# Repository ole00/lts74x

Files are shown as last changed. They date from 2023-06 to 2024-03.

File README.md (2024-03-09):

# lts74x
Yet another 74x-series IC logic tester that uses Arduino board for testing the logic states of the IC.

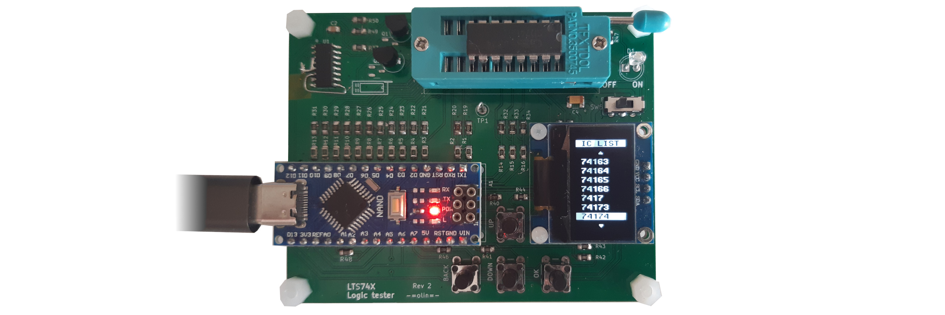
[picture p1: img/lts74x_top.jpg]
Board image lts74x


Lts74x was inspired by the following propjects:
* Integrated circuit tester: https://github.com/Johnlon/integrated-circuit-tester
* Smart IC Tester: https://github.com/akshaybaweja/Smart-IC-Tester

Features:
* Uses Arduino Nano and one GPIO Expander IC
* Tests many 16 and 18 pin 74x series ICs, test database is based on the above projects.
* Tests some 20 pin 74x series ICs, requires Arduino Nano modification (LED and pull resistor removals)
* Uses OLED screen for IC selection
* Displays basic IC pinout and indicates failed pins after the test.
* Screen saver to prevent OLED screen burn.
* Supports testing Z states on IC pins.
* Supports Clock pin.
* Supports latched pin testing.
* Tests are compressed to fit into Arduino Nano flash (still about ~4 kb free).
* Open source / hardware design (kicad), schematics and gerbers provided.
* Basic Arduino pin protection via 1k Ohm resitor in series (we test ICs that might be broken internally).

Setup:
-----------
 * Upload the lts74x20.ino sketch to your Arduino Nano. Use Arduino IDE to upload the sketch, both IDE version 1.8.X and 2.X should work fine.
   Note that some USB-C based Arduino Nano clones require to select Tools-> Processor ->ATMegae328P (Old Bootloader) to flash them.
 * Decide whether you want/need the 20pin IC test feature. If so, modify the Arduino board - see Arduino mod in Q&A section.
 * Build the lts74x hardware. Buy the PCB from an online PCB production service (use provided gerber archive in 'gerbers' directory).
   Then solder the components on the PCB - check the schematic (lts74x.pdf) and bom.txt for parts list.

How lts74x works:
------------------
* The IC tester works on it own, that means it does not need a PC serial connection in order to test the IC chips.
* After start, the IC list is displayed on the screen and you can select the IC you want to test by pressing
 Up and Down buttons. Selection is confirmed by the OK button. You can also check the basic pinout of the device
 by pressing the Back button.
* Pressing the OK button starts the IC testing (the switch powering the IC must be switched on - the app dectects
 that and asks you to flip the switch if the switch is Off). Of course, you should insert the actual IC in the ZIF
 socket beforehand to get meaningful test results. Insert the IC while the power switch is Off (which prevents accidental zapping of
 the IC during insertion), then you can turn the Power switch On and start the test.

* Each IC has its own set of tests stored in the flash. Upon pressing OK, the test set is loaded, decoded and then run 100 times.
  Note that the test set is comprised of several individual tests that check the different input pin combinations (High, Low inputs)
  and output results (High, Low, Z state outputs). The whole testing set is run and if there is an error the IC pinout with
  failed pins is displayed on the screen.

* Each test is defined as a text string where each character in the string corresponds to a certain pin state. Pins marked as 0 or 1
  are the IC input pins and their value is set via Arduino to the desired value (Low or High repsectively). Pins marked
  as L, H or Z are the IC output pins and their value is read by Arduino and evaluated. L marked pins must read digital 0, H marked
  pins must read digital 1 from the correspondig GPIO. Z marked pins test the high impedance output (see Q&A section for details) 
  of the IC chip.
  
PCB:
-----------
 The most convenient way to get the PCB is to order it online on jlcpcb.com, pcbway.com, allpcb.com or other online services. 
 Use the zip archive stored in the gerbers directory and upload it to the manufacturer's site of your choice. 
 Upload the lts74x_r3_fab.zip and set the following parameters (if required).

  * Dimensions are 85x68 mm
  * 2 layer board
  * PCB Thickness: 1.6, or 1.2 mm
  * Copper Weight: 1
  * The rest of the options can stay default or choose whatever you fancy (colors, finish etc.)

Soldering/assembly steps:
--------------------------
  * start with the smallest parts, solder the resistors and capacitors.
  * Use multimeter and verify the resistance between Arduino pins and GND (Test point TP1). It should be ~ 470kOhm.
  * Use multimeter and verify the resistance between Arduino pins the corresponding ZIF socket pin - It should be 1kOhm. 
  * To do the above, check the schematics PDF to find out which Arduino pins lead to which ZIF socket pin.
  * solder the U1 IC. 
  * solder the  Q1 and Q2 Mosfets. Note that there is a dual footprint for the Mosfets, use either Through-Hole footrpint or SMT fotrpint, but not
    both at the same time.  Important: use low soldering temeprature (no more that 280 C)
    to prevent the Mosfet damage. While soldering, touch the Mosfets pins for only a very short time (2 seconds max). If you need
    to improve the soldering joint, let the Mosfet to cool down a bit, apply a flux on the pin and then briefly touch upon the pin with the soldering tip.
    I managed to burn 2 Mosfets while doing so with higher temperature. To test the Mosfet is OK use multimeter and test resistance between Ground pin
    (Source) and the Drain pin while the board in powered off. The resistance value must be ~ 470kOhm. If it is way less than that (like 2kOhm) 
    the Mosfet gate was damaged during soldering.
  * Solder the LED
  * Solder the power switch
  * Test your OLED display on a breadboard connected to Arduino and a test sketch whether the display actually works.
    I got an LCD delivered which was faulty, so I had to use another one. Returning a faulty OLED display to the seller might be problematic
    if there are traces of soldering on the display. While running the OLED test, check which I2C address it uses.
  * Solder the OLED display. Before you do that, use M2 bolt and nuts to secure the display to the PCB. Use extra M2 nuts in between the OLED display
    and and the tester PCB as a spacer.
  * Solder the buttons
  * Optionally, solder the Arduino female header socket on the tester PCB if you want to have your Arduino Nano detachable.
  * Optionally, mod your Arduino Nano to support 20 pin IC testing capability (see Q&A section).
  * Verify the 5V pin and Ground is not shorted - use multimeter and continuity test to do that. Very short initial beep might be OK as that
    might be the decoupling capacitors letting through the probing current.
  * Insert/solder the Arduino Uno.
  * Power the Board on by plugging-in the USB cable. Test the basic functionality (buttons, power switch and LED, test an IC with no IC inserted/used).
    If they do not work, check the troubleshooting.

  * Solder the ZIF socket.

Q&A:
---------------
* I can't upload the sketch to my my Arduino Nano clone because of a communication error
   - Nano clones often use CH340 serial chip (or in my case, a clone of the CH340 chip). When using Windows or Mac,
     make sure you have the CH340 serial driver installed. See : https://learn.sparkfun.com/tutorials/how-to-install-ch340-drivers/all
   - Ensure Arduino Nano is selected in the Arduino IDE: Tools -> Board: Arduino Nano
   - Try setting the Processor option Old Bootloader: Tools-> Processor ->ATMega328P (Old Bootloader)

* I turned it on and the OLED display does not show anything
   - Ensure lts74x20.ino sketch was uploaded to your Arduino Nano.
   - Did you do the OLED test as described in Assembly steps? Check the OLED screen communicates via I2C 
     by running I2C scanner sketch: File -> Examples -> Wire -> i2c_scanner. It should find 2 devices:
     one is the GPIO Expander address 0x18 and the second one is the OLED screen using address 0x78.
     Modify OLED_ADDRESS value in lts74x20.ino sketch if your OLED address is different.

* what is the On switch used for? When do I use it?

    - Normally, the switch should be in the Off position (LED is not lit). Also when insering the IC chip or when removing the IC chip
      from the ZIF socket the switch should be Off. Just before you start the test the switch should be turned On.
      So in general: insert the IC when the switch is Off, then turn the switch On and run the test. When finished turn the switch Off,
      and remove the IC chip from the socket.

* I tested a brand new IC chip and it fails during the test. Some pins (or a single pin) indicate a failure.
    - Double check all resistors leading to the ZIF socket pins (1 kOhm) and weak pull down resistors (470 kOhm) are well soldered.
     There might be a missing solder joint on that particular pin or on a pin that contributes to the logical output of the failed pin.
     Test the resistance by attaching multimeter probes to an Arduin pin and corresponding ZIF socket pin, and also between
     the Arduino pin and ground (TP1).

* The site image on the very top shows some bodge wires connected to U1 - shall I be concerned?
  - No, there is no need to replicate that on your board. The image shows a prototype board (Revision 2) that has a bug which was fixed in 
    board Revision 3. Rev. 3 is currently the one available for download.
  
* What is the mod to let me test 20 pin ICs?
    - See image bellow. Basically, remove few pull resistors (marked red on the bellow image) by touching them with a hot soldering iron (~350C) for 4 seconds and then
      while pushing them a bit sideways they will slide-off of its footprints on the PCB.
      **Important:** before doing the mod make sure the Arduino sketch is uploaded. After the mod is done, it won't be possible to upload the sketch
      via USB. Uploading will be possible, but it is less convenient and requires another Arduino board.
    - remove the RX and TX resistors or LEDs on the top. 
    - remove the L resistor or LED on the top
    - remove the resistors on the bottom of the board. Please note that my Arduino nano is a clone, it does not even use a genuine CH340
       serial chip. If you have a different Arduino Nano board than the one pictured bellow, then you may need to remove other resistors
       or it might be more convenient to remove the serial chip itself.
    - solder headers to allow sketch reprogramming in the future (marked green on the bellow image)
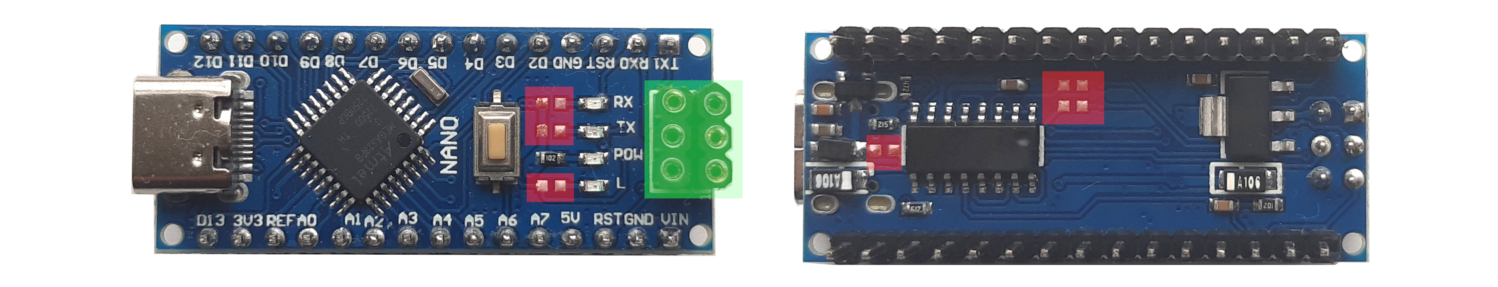
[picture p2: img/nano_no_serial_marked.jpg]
Board image Nano serial mod - click to zoom


* How is the Z state stested?
    - The Z - or High impedance - state test is based on 2 following facts: 
    - The lts74x circuit has very weak external pull down resistors (470k Ohm) on all ZIF pins. During testing of High or Low states this pull down resistor
      does not affect the results read from the pins, because IC currents are much stronger.
    - The IC pin in Z state should not source or sink any current from the wire connected to the pin (if it does, it is an error).
     Therefore the pin's current (if there is any teeny tiny one) should not have enough 'strength' to override the actual state of the wire
     leading to the pin. So, if the Arduino sets a pin leading to the IC's Z pin as Input with internall Pull up (~30k Ohm), then Arduino should 
     read it as High. Also, if Arduino sets a pin leading to the IC's Z pin as Input (external pull down, see above) then Arduino should
     read it as Low. If the reeading is incorrect then the IC's pin is not in the Z state as it 'overrides' the pull resistors by sinking or 
     sourcing the current. That means it's not in Z state and the pin is malfunctioning or is damaged. The Z test does exactly that:
     sets the pin as Input with internal pull up and reads the value, then sets it as Input with external pull down and reads the value.
     If the read values are correct the pin is in Z state. There are few more details involved in the actuall Z test (like there must be a small
     delay allowing the pull resistor to react before reading the value etc.), so check the source code if you are interested.

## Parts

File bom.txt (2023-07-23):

BOM for lts74x rev 3
--------------------------------------------------------------------------------
"Item","Qty","Reference(s)","info"

"1","1","A1","Arduino_Nano_v3.x","http://www.mouser.com/pdfdocs/Gravitech_Arduino_Nano3_0.pdf"
"2","1","C2","0.1u -  Capacitor_SMD:C_0805_2012Metric"
"3","1","C4","22u - Capacitor_SMD:C_1210_3225Metric"
"4","1","D1","LED","LED_THT:LED_D5.0mm"
"5","1","J1","ZIF Socket 02x10 narrow 2.54mm pin pitch Package_DIP:DIP-20_W7.62mm"
"6","1","J2","OLED SSD1306 Connector_PinHeader_2.54mm"
"7","2","Q1, Q2","N_MOSFET Enhancement Package_TO_SOT_SMD:SOT-23-3 Any N mosfet enhancement with low-ish RDS On value"
"8","19","R1, R2, R3, R4, R5, R6, R7, R8, R9, R10, R11, R12, R13, R14, R15, R16, R17, R18, R47","1k","Resistor_SMD:R_0805_2012Metric"
"9","18","R19, R20, R21, R22, R23, R24, R25, R26, R27, R28, R29, R30, R31, R32, R33, R34, R35, R36","470k","Resistor_SMD:R_0805_2012Metric"
"10","11","R37, R38, R39, R40, R41, R42, R43, R44, R45, R49, R50","10k","Resistor_SMD:R_0805_2012Metric"
"11","2","R46, R48","2k2","Resistor_SMD:R_0805_2012Metric"
"12","4","SW1, SW2, SW3, SW4","Button_Switch_THT:SW_PUSH_6mm"
"13","1","SW5","SW_Push_DPDT - Button_Switch_THT EG1271_SPDT"
"14","1","U1","PCA9557D","GPIO expander Package_SO:SO-16_3.9x9.9mm_P1.27mm","https://www.nxp.com/docs/en/data-sheet/PCA9557.pdf"

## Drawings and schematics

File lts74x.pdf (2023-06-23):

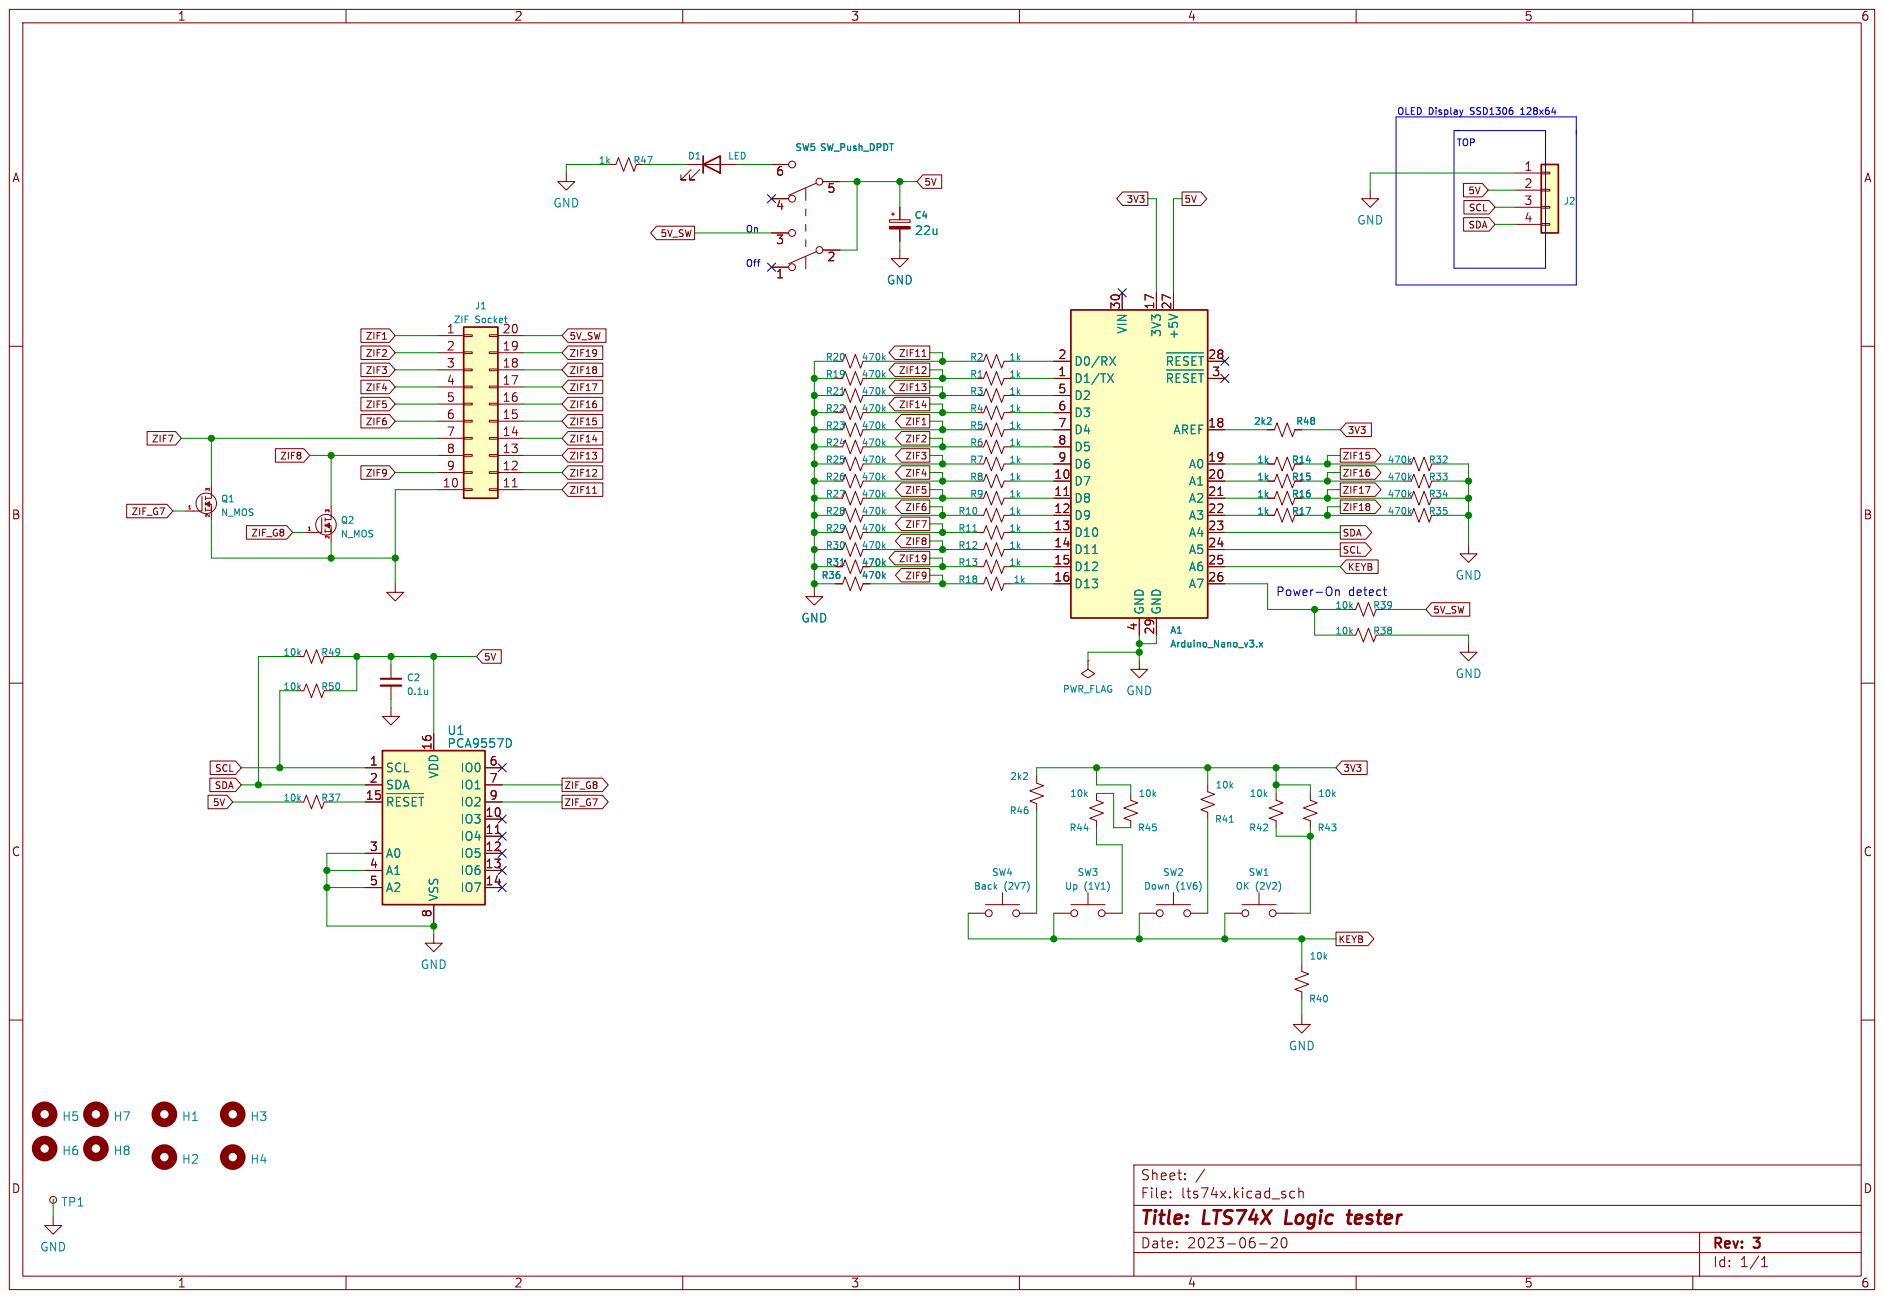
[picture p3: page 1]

Id: 1/1 Title: LTS74X Logic tester File: lts74x.kicad_sch Sheet: /

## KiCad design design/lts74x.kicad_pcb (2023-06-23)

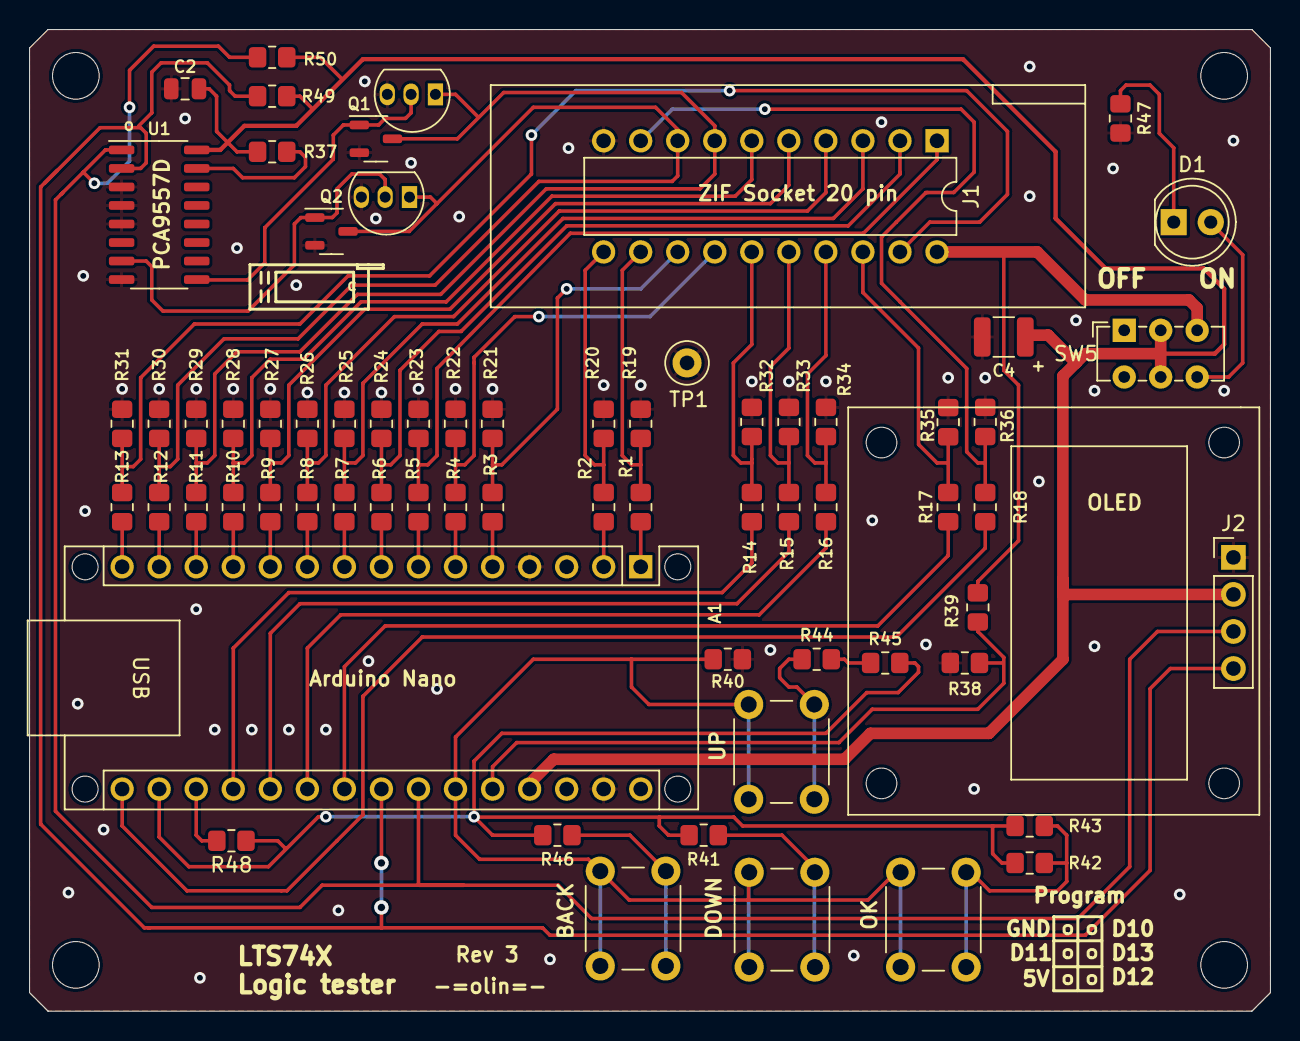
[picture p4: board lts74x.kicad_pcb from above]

Board: 2 copper layers, 85.1 x 67.3 mm, 75 parts (0 on the bottom side), 55 nets.

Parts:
A1: Arduino_Nano_v3.x; Arduino_Nano_WithMountingHoles
C2: 0.1u; C_0805_2012Metric
C4: 22u; C_1210_3225Metric
D1: LED; LED_D5.0mm
H1, H2, H3, H4: MountingHole; MountingHole_3.2mm_M3
H5, H6, H7, H8: MountingHole; MountingHole_2.1mm
J1: ZIF Socket; DIP-20_W7.62mm
J2: OLED SSD1306; PinHeader_1x04_P2.54mm_Vertical
Q1, Q2#2: N_MOS; SOT-23-3
Q1#2, Q2: TO-92L_Inline
R1, R2, R3, R4, R5, R6, R7, R8, R9, R10, R11, R12, R13, R14, R15, R16, R17, R18, R47: 1k; R_0805_2012Metric_Pad1.20x1.40mm_HandSolder
R19, R20, R21, R22, R23, R24, R25, R26, R27, R28, R29, R30, R31, R32, R33, R34, R35, R36: 470k; R_0805_2012Metric_Pad1.20x1.40mm_HandSolder
R37, R38, R39, R40, R41, R42, R43, R44, R45, R49, R50: 10k; R_0805_2012Metric_Pad1.20x1.40mm_HandSolder
R46, R48: 2k2; R_0805_2012Metric_Pad1.20x1.40mm_HandSolder
SW1: OK (2V2); SW_PUSH_6mm
SW2: Down (1V6); SW_PUSH_6mm
SW3: Up (1V1); SW_PUSH_6mm
SW4: Back (2V7); SW_PUSH_6mm
SW5: SW_Push_DPDT; SW_E-Switch_EG1271_SPDT
TP1: TestPoint_Small; TestPoint_Loop_D2.50mm_Drill1.0mm
U1: PCA9557D; SO-16_3.9x9.9mm_P1.27mm

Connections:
3V3: A1.17 (3V3), R41.2, R42.2, R43.2, R45.2, R46.2, R48.1
5V: A1.27 (+5V), C2.1, C4.1, J2.2, R37.2, R49.1, R50.1, SW5.2 (B), SW5.5 (B), U1.16 (VDD)
5V_SW: J1.20, R39.1, SW5.3 (C)
GND: A1.4 (GND), A1.29 (GND), C2.2, C4.2, J1.10, J2.1, Q1.2, Q1#2.3, Q2.3, Q2#2.2, R19.1, R20.1, R21.1, R22.1, R23.1, R24.1, R25.1, R26.1, R27.1, R28.1, R29.1, R30.1, R31.1, R32.1, R33.1, R34.1, R35.1, R36.1, R38.1, R40.1, R47.2, TP1.1, U1.3 (A0), U1.4 (A1), U1.5 (A2), U1.8 (VSS)
KEYB: A1.25 (A6), R40.2, SW1.1, SW2.1, SW3.1, SW4.1
unnamed: A1.19 (A0), R14.2
unnamed: A1.20 (A1), R15.2
unnamed: A1.21 (A2), R16.2
unnamed: A1.22 (A3), R17.2
unnamed: A1.26 (A7), R38.2, R39.2
unnamed: A1.18 (AREF), R48.2
unnamed: A1.2 (D0/RX), R2.2
unnamed: A1.1 (D1/TX), R1.2
unnamed: A1.5 (D2), R3.2
unnamed: A1.6 (D3), R4.2
unnamed: A1.7 (D4), R5.2
unnamed: A1.8 (D5), R6.2
unnamed: A1.9 (D6), R7.2
unnamed: A1.10 (D7), R8.2
unnamed: A1.11 (D8), R9.2
unnamed: A1.12 (D9), R10.2
unnamed: A1.13 (D10), R11.2
unnamed: A1.14 (D11), R12.2
unnamed: A1.15 (D12), R13.2
unnamed: A1.16 (D13), R18.2
unnamed: D1.2 (A), SW5.6 (C)
unnamed: D1.1 (K), R47.1
unnamed: R41.1, SW2.2
unnamed: R42.1, R43.1, SW1.2
unnamed: R44.1, SW3.2
unnamed: R44.2, R45.1
unnamed: R46.1, SW4.2
unnamed: R37.1, U1.15 (~RESET)
SCL: A1.24 (A5), J2.3, R50.2, U1.1 (SCL)
SDA: A1.23 (A4), J2.4, R49.2, U1.2 (SDA)
ZIF1: J1.1, R5.1, R23.2
ZIF2: J1.2, R6.1, R24.2
ZIF3: J1.3, R7.1, R25.2
ZIF4: J1.4, R8.1, R26.2
ZIF5: J1.5, R9.1, R27.2
ZIF6: J1.6, R10.1, R28.2
ZIF7: J1.7, Q1.3, Q1#2.1, R11.1, R29.2
ZIF8: J1.8, Q2.1, Q2#2.3, R12.1, R30.2
ZIF9: J1.9, R18.1, R36.2
ZIF11: J1.11, R2.1, R20.2
ZIF12: J1.12, R1.1, R19.2
ZIF13: J1.13, R3.1, R21.2
ZIF14: J1.14, R4.1, R22.2
ZIF15: J1.15, R14.1, R32.2
ZIF16: J1.16, R15.1, R33.2
ZIF17: J1.17, R16.1, R34.2
ZIF18: J1.18, R17.1, R35.2
ZIF19: J1.19, R13.1, R31.2
ZIF_G7: Q1.1, Q1#2.2, U1.9 (IO2)
ZIF_G8: Q2.2, Q2#2.1, U1.7 (IO1)

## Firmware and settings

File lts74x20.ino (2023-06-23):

/*
 Logic tester for 74XX 14,16,20 pin ICs
 */

 #define VERSION " V. 0.2"

// Use debug when testing 14 or 16 pin chps. Uart pins (0,1) are
// used to test 20 pin chips - therefore disable debug
// when full 20 pin testing functionality is required.

#define SHOW_DEBUG 0

// Enable TEST_KEYS to check key/button values as read by ADC during start-up
#define TEST_KEYS 0

// Enable TEST_IO_EXPANDER to test IO expander pins P1 and P2 (P0 is not used)
#define TEST_IO_EXPANDER 0

// OLED DISPLAYS with silkscreened address 0x3C (0b111100) work with OLED_ADDRESS value set to 0x78 (0b1111000)
#define OLED_ADDRESS 0x78

// IO Expander I2C Address (PCA9557D), PINS A0,A1,A2 are all tied to GND
#define IO_ADDR 0x18


#include <EEPROM.h>

//index                           0  1  2  3  4  5  6    7   8          9  10  11  12  13  14  15  16  17
//IC pins                         1  2  3  4  5  6  7    8   9  GND-10 11  12  13  14  15  16  17  18  19  VCC-20
static const uint8_t pins[18]  = {4, 5, 6, 7, 8, 9, 10, 11, 13,         0,  1,  2,  3, A0, A1, A2, A3, 12};

// "E: test string is null!"
#define ERR_TEST_STRING_NULL 1

// "E: setPins: malformed config string!"
#define ERR_TEST_FORMAT 2

// "E: GND definition is incorrect!"
#define ERR_TEST_GND 3

// "E: VCC definition is incorrect!"
#define ERR_TEST_VCC 4

// "Test not found"
#define ERR_TEST_NOT_FOUND 5

uint8_t errors[16] = {0}; //index 0 holds number of errors
    
// the test data database
#include "ic_dbase.h"

// OLED screen drawing
#include "oled_ssd1306.h"

#define STATE_MENU 0
#define STATE_TEST 1
#define STATE_RESULT 2
#define STATE_PINOUT 3
#define STATE_SHOW_ERRORS 4
#define STATE_SCREEN_SAVER 5

#define PIN_KB     A6

#define PIN_VCC_DETECT A7

#define ADC_LEFT  874
#define ADC_UP    354
#define ADC_DOWN  532
#define ADC_RIGHT 710

#define KEY_BACK  1
#define KEY_UP    2
#define KEY_DOWN  3
#define KEY_OK    4

#define MENU_ITEMS 7

#define FILL_FLAG 0x80

// About 5 minutes (value 6000)
#define SCREEN_SAVER_TIMEOUT 6000


uint8_t state;
uint8_t key;

uint8_t icIndex = 0; // currently selected IC index in the list 
uint8_t topIndex = 0; // index of the first item displayed in the IC list

int8_t scrSaverX = -7;
int8_t scrSaverY = 8;
int8_t scrSaverIncX = 1;
int8_t scrSaverIncY = 1;

static uint8_t prevHighlight = 0;

static void handleTestResults(char* pinout, char* result, uint8_t errors);

// Load variables from EEPROM
static void loadVariables(void) {
    if (EEPROM.read(0) != 0x74 || EEPROM.read(1) != 0x1E) {
        topIndex = 0;
        icIndex = 0;
        return;
    }
    topIndex = (int8_t) EEPROM.read(2);
    icIndex = (int8_t) EEPROM.read(3);
}

// Save Variables to EEPROM
static void saveVariables(void) {
    EEPROM.update(0, 0x74);
    EEPROM.update(1, 0x1E);
    EEPROM.update(2, topIndex);
    EEPROM.update(3, icIndex);
}

// Simple error loggging to be displayed on the OLED screen/
static void addError(uint8_t e) {
    uint8_t errCount = errors[0];
    if (errCount < 14) {
      errCount++;
      errors[0] = errCount;
      errors[errCount] = e;
    }
}

// set IO Expaner P1 and P2
// 0: P1 and P2 to 0 - no GND on ZIF7 and ZIF8 pins
// 1: ZIF7 GND 
// 2: ZIF8 GND
static void setGnd(uint8_t gndPins) {
    uint8_t val = 0;
    if (gndPins) {
        val = (gndPins == 1) ? 0b100 : 0b10;
    }
    
    Wire.beginTransmission(IO_ADDR);
    // command 1: set output port 
    Wire.write(1);
    Wire.write(val); // P1 and P2 are outputs
    Wire.endTransmission();
}

// Set pins based on the test configuration string.
static void setPins(char* cfg, uint8_t pinCount) {
    uint8_t i, pinIndex;
    uint8_t p;
    uint8_t clockPin = 0xFF;
    uint8_t latchPin = 0xFF; // when latch pin is detected all '0' and '1' will be flipped after the latch is set
    uint8_t flipInput = 0;

    if (cfg == NULL) {
        addError(ERR_TEST_STRING_NULL);
        return;
    }


    //handle special flags at the start
    if (cfg[0] == 'F') {
        cfg++;
        flipInput = 1;
    }
    
    //sanity check
    if (strlen(cfg) < pinCount) {
        addError(ERR_TEST_FORMAT);
        return;
    }

#if SHOW_DEBUGx
    Serial.print("Testing: ");
    Serial.println(cfg);
#endif


    pinIndex = 0;
    for (i = 0; pinIndex < 18 && cfg[i] != 0; i++) { // do not process the last pin: VCC
        p = pins[pinIndex];
        switch (cfg[i]) {
            case 'C':
                clockPin = p;
                // fall through
            case 'D': //disable pin: low (no flip)
                //fall through
            case '0':
                pinMode(p, OUTPUT);
                digitalWrite(p, 0);
                pinIndex++;
                break;
            case 'A':
                latchPin = p; // latch pin is normally high then when all the rest is set it goes low
                //fall through
            case 'E': //enable pin: high (no flip)
                //fall through
            case '1':
                pinMode(p, OUTPUT);
                digitalWrite(p, 1);
                pinIndex++;
                break;
            case 'H':
            case 'Z':
            case '?':
                pinMode(p, INPUT);
                pinIndex++;
                break;
            case 'X':
                pinMode(p, INPUT);
                pinIndex++;
                break;
            case 'L': // if expecting low state then set a pull up to ensure the pin was actively driven low
            case 'U': //new state - maybe not required?
                pinMode(p, INPUT_PULLUP);
                pinIndex++;
                break;
            case  'G':
                if (pinCount == 14 && pinIndex == 6) {
                    pinIndex = 12;
                } else
                if (pinCount == 16 && pinIndex == 7) {
                    pinIndex = 11;
                } else
                if (!(pinCount == 20 && pinIndex == 9)) {
                    addError(ERR_TEST_GND);
                }
                break;
            case  'V':
                addError(ERR_TEST_VCC);
                break;
            // any other character is ignored
        }
    }

    //handle clock pin (assume it was set as output already)
    if (clockPin != 0xFF) {
        delayMicroseconds(100);
        digitalWrite(clockPin, 1);
        delayMicroseconds(100);
        digitalWrite(clockPin, 0);
    }

    // exit if there is no latch pin
    if (latchPin == 0xFF) {
        delayMicroseconds(100);
        return;
    }


    //handle latch pin (assume it was set as output high already)
    delayMicroseconds(100);
    digitalWrite(latchPin, 0);
    delayMicroseconds(100);


    // exit if flipping the input pins is not required
    if (!flipInput) {
        return;
    }

    //flip '0's and '1's. The expected outputs should not be changed as the latch was already set
    pinIndex = 0;
    for (i = 0; pinIndex < 18 && cfg[i] != 0; i++) { // do not process the last pin: VCC
        p = pins[pinIndex];
        switch (cfg[i]) {
            case '0':
            case '1':
                digitalWrite(p, '1' - cfg[i] );  //set the inverted value
                pinIndex++;
                break;

            case 'C':
            case 'A':
            case 'H':
            case 'Z':
            case '?':
            case 'X':
            case 'L': 
            case 'U': 
            case 'E': 
            case 'D': 
                pinIndex++;
                break;
            case  'G':
                if (pinCount == 14 && pinIndex == 6) {
                    pinIndex = 12;
                } else
                if (pinCount == 16 && pinIndex == 7) {
                    pinIndex = 11;
                } else
                if (!(pinCount == 20 && pinIndex == 9)) {
                    addError(ERR_TEST_GND);
                }
                break;
            case  'V':
                addError(ERR_TEST_VCC);
                break;
            // any other character is ignored
        }
    }
    delayMicroseconds(100);
    
}

// Test the results by reading pins marked as inputs (H or L or Z)
// returns number of failed pins
static unsigned char testPins(char* cfg, char* testResult, uint8_t pinCount) {
    unsigned char res = 0;
    unsigned char i, pinIndex;
    if (cfg == NULL) {
        addError(ERR_TEST_STRING_NULL);
        return 0xFF;
    }

    //handle special flags at the start
    if (cfg[0] == 'F') {
        cfg++;
    }
    
    //sanity check
    if (strlen(cfg) < pinCount) {
        addError(ERR_TEST_FORMAT);
        return 0xFF;
    }

    pinIndex = 0;
    for (i = 0; pinIndex < 18 && cfg[i] != 0; i++) { //do not test the last pin: VCC
        uint8_t p = pins[pinIndex];
        switch (cfg[i]) {
            case '0':
            case 'C':
            case '1':          
            case 'E':
            case 'D':
                pinIndex++;
                break;
            case 'H':
                if (digitalRead(p) != 1) {
                    res++;
                    testResult[i] = 'E';
                }
                pinIndex++;
                break;
            case 'L':
                if (digitalRead(p) != 0) {
                    res++;
                    testResult[i] = 'E';
                }
                pinIndex++;
                break;
            case 'Z':
                {
                    uint8_t x = 0;
#if SHOW_DEBUG                    
                    Serial.print("Test pin: ");
                    Serial.println(pinIndex);
#endif
                    while(x++ < 4){
                        pinMode(p, OUTPUT);
                        digitalWrite(p, 0); // force the pin Low
                        delayMicroseconds(20);
                        pinMode(p, INPUT_PULLUP); //weak internal pull up should raise the pin High
                        delayMicroseconds(100);
                        if (digitalRead(p) != 1) { //test the pin is High
                            res++;
                            testResult[i] = 'E';
                        }
                        digitalWrite(p, 1); // force the pin High
                        delayMicroseconds(20);
                        pinMode(p, INPUT); //weak external pull down should set the pin Low
                        delayMicroseconds(100);
                        if (digitalRead(p) != 0) { //test the pin is Low
                            res++;
                            testResult[i] = 'E';
                        }
                    }
                    pinIndex++;
                }
                break;
            case '?':
            case 'S':
                // TODO - implement ?
                pinIndex++;
                break;
            case 'X':
            case 'A':
                //pinIndex++;
                pinIndex++;
                break;
            case  'G':
                if (pinCount == 14 && pinIndex == 6) {
                    pinIndex = 12;
                } else
                if (pinCount == 16 && pinIndex == 7) {
                    pinIndex = 11;
                } else
                if (!(pinCount == 20 && pinIndex == 9)) {
                    addError(ERR_TEST_GND);
                }
                break;
            case  'V':
                addError(ERR_TEST_VCC);
                break;
            // any other character is ignored
        }
    }
    testResult[i] = 0;

#if SHOW_DEBUG
    if (res) {
        Serial.print("Errors: ");
        Serial.println(res);
    }
#endif
    return res;    
}

#if SHOW_DEBUG
static void printTestResult(unsigned char res, char* cfg) {
    if (res) {
        Serial.println(F("Test FAILED."));       
        Serial.print(cfg);
        Serial.print(F(" ("));
        Serial.print(res);
        Serial.println(F(" errors)"));
    }
#if 1
    else {
        Serial.println(F("Test PASSED."));
    }
#endif
}
#endif

// Decompress/decode one test string stored in flash.
static void decodeProgmemStr(char* dst, const char* src, uint16_t max) {
    uint16_t i, len;
    uint16_t pos = 0;
    char c;

    len = strlen_P(src);

    for (i = 0; i < len; i++) {
        char replace4 = 0;
        c = pgm_read_byte_near(src + i);
        if (c == '-') {
            replace4 = '0';
        } else
        if (c == '+') {
            replace4 = '1';
        } else
        if (c == '*') {
            replace4 = 'H';
        } else
        if (c == '/') {
            replace4 = 'L';
        } else
        if (c == '[') {
            replace4 = 'Z';
        }

        // replace 1 character by 4 characters
        if (replace4) {
            c = 4;
            while (c--) {
                dst[pos++] = replace4;
            }
        } else
        // replace 1 character by 2 characters
        if (c >= 'a' && c <= '}') {
            uint8_t ti = c - 'a';
            ti <<= 1;
            dst[pos++] = pgm_read_byte_near(decode_tokens + ti);
            dst[pos++] = pgm_read_byte_near(decode_tokens + ti + 1);
        } else {
            //copy the character
            dst[pos++] = c;
        }
        if (max && pos >= max) {
          i = len; //exit the loop
        }
    }
    dst[pos] = 0;

}

// Copies string stored in flash to a RAM buffer.
static void copyProgmemStr(char* dst, const char* src, uint8_t max) {
    uint16_t i, len;
    uint8_t fill = max & FILL_FLAG;

    max &= 0x7F; //remove FILL flag

    len = strlen_P(src);
    if (max && max < len) {
        len = max - 1;
    }
    for (i = 0; i < len; i++) {
        dst[i] = pgm_read_byte_near(src + i);
    }
    if (fill) {
        if (len < max) {
            while (i < max) dst[i++] = ' ';
        }
        dst[max] = 0;
    } else {
        dst[i] = 0;
    }
}

// Splits the test line into individual tests.
static int16_t splitTests(char* testLine, char** tests, uint8_t maxTest) {
    uint16_t i,t;

    if (NULL == testLine) {
        return 0;
    }
    i = 0;
    t = 0;
    tests[t] = testLine;
    while (testLine[i] != 0) {
        if (testLine[i] == ' ') {
            testLine[i] = 0;
            if (t < maxTest - 1) {
                t++;
                tests[t] = testLine + i + 1;
            }
        }
        i++;
    }
    return t + 1;
}


// Main testing function. Pass an index of the device to test.
static void performIcTest(int16_t i) {
    uint16_t err = 0;
    int16_t total;
    char cfg[530]; //Serial.println runs out of stack when more than 530 bytes are allocated
    char testResult[22];
    char* tests[32];

    // Display "TESTING ..." screen
    oled_clear_display();
    {
        char* buf = testResult;
        copyProgmemStr(buf, (const char*) F(" TESTING"), 0);
        oled_set_y(24);
        oled_draw_string(buf, false);

        copyProgmemStr(buf, (const char*) F("   ..."), 0);
        oled_set_y(64);
        oled_draw_string(buf, false);
    }

    // ensure the testResult is an empty string filled with space
    for (total = 0; total < 21; total++) {
        testResult[total] = 32;
    }
    testResult[21] = 0;


#if SHOW_DEBUG
    Serial.println(F("---[Testing]----------------------"));
#endif    
    
    if (i > 0) {
        uint8_t pinCount;
        uint8_t gndPins = 0;
        decodeProgmemStr(cfg, ic_tests[i], 528);

#if SHOW_DEBUG
        Serial.println(cfg);
#endif
        total = splitTests(cfg, tests, 32);
#if SHOW_DEBUG
        Serial.print("Found ");
        Serial.print(total);
        Serial.println(" tests.");
        for (i = 0; i < total; i++) {
            Serial.println(tests[i]);
        }
#endif        
        pinCount = strlen(tests[0]);
        // special character exists ?
        if (tests[0][0] == 'F') {
            pinCount--;
        }

        if (pinCount == 14) {
            gndPins = 1;
        } else
        if (pinCount == 16) {
            gndPins = 2;
        }
        setGnd(gndPins);
#if SHOW_DEBUG
        Serial.print(F("gndPulse"));
        Serial.println(gndPulse, DEC);
#endif

        // run all tests X times
        for (i = 0; i < 100; i++) {
            unsigned char t, r;
            unsigned char testCnt = 4;
            for (t = 0; t < total; t++) {
                setPins(tests[t], pinCount);
                r = testPins(tests[t], testResult, pinCount);
                //printTestResult(r, testResult);
                err += r;
            }
            if (err) { //errors detected
                i  = 100; //break from the loop
            }
        }
        //unset all pins
        for (i = 0; i < 18; i++) {
#if SHOW_DEBUG
           if (i != 9 && i != 10)
#endif          
            pinMode(pins[i], INPUT);
            delayMicroseconds(1);
        }
        setGnd(0); //no GND pins 
    } else {
        addError(ERR_TEST_NOT_FOUND);
    }

    // Fatal error occured: display error list
    if (errors[0]) {
        state = STATE_SHOW_ERRORS;
    }
    // Display test results
    else {
        handleTestResults(tests[0], testResult, err);
    }
}

// This is a debugging / troubleshooting version of the above.
// It runs only one test and waits 3 seconds so that the problematic
// pins can be scoped or measured by multimeter. After 3 seconds
// The pin settings are reset and the test is repeated.
// Note that you have to alter the test index.
static void performIcTest2(int16_t i) {
    uint16_t err = 0;
    int16_t total;
    char cfg[530]; //Serial.println runs out of stack
    char testResult[22];
    char* tests[32];
    char* buf = testResult;

    // Display "TESTING ..." screen
    oled_clear_display();
    {
        copyProgmemStr(buf, (const char*) F(" TESTING"), 0);
        oled_set_y(24);
        oled_draw_string(buf, false);

        copyProgmemStr(buf, (const char*) F("   .o."), 0);
        oled_set_y(64);
        oled_draw_string(buf, false);
    }

    // ensure the testResult is an empty string filled with space
    for (total = 0; total < 21; total++) {
        testResult[total] = 32;
    }
    testResult[21] = 0;

  
    
    if (i > 0) {
        uint8_t j;
        uint8_t pinCount;
        uint8_t gndPins = 0;
        decodeProgmemStr(cfg, ic_tests[i], 528);

#if SHOW_DEBUG
        Serial.println(cfg);
#endif
        total = splitTests(cfg, tests, 32);
#if SHOW_DEBUG
        Serial.print("Found ");
        Serial.print(total);
        Serial.println(" tests.");
        for (i = 0; i < total; i++) {
            Serial.println(tests[i]);
        }
#endif
        pinCount = strlen(tests[0]);

        if (pinCount == 14) {
            gndPins = 1;
        } else
        if (pinCount == 16) {
            gndPins = 2;
        }
        //setGnd(gndPins); // OLED off, GNDs on

        // run all tests X times
        for (i = 0; i < 100; i++) {
            unsigned char t, r;
            unsigned char testCnt = 4;

            setGnd(gndPins);
            delayMicroseconds(100);

            setPins(tests[2], pinCount); // <<=== here change the test index
            pinMode(pins[10], INPUT);
            delayMicroseconds(100);
            r  = digitalRead(pins[1]);
            delay(3000);
            //unset all pins
            for (j = 0; j < 18; j++) {
    #if SHOW_DEBUG
              if (j != 9 && j != 10)
    #endif          
                pinMode(pins[j], INPUT);
                delayMicroseconds(1);
            }
            setGnd(0); //no GND pins

            if (r == 0) {
               copyProgmemStr(buf, (const char*) F("    0"), 0);
            } else {
               copyProgmemStr(buf, (const char*) F("    1"), 0);
            }
            oled_set_y(64);
            oled_draw_string(buf, false);
        }
    }
}


// Checks whether particular button / key was pressed by comparing 
// analogue value with preset value.
static uint8_t isKbPressed(uint16_t r, uint16_t val) {
  return  (val - 10 < r && r < val + 10);
}

// Returns a key code of a pressed key or 0 if no key is pressed.
static uint8_t checkKb() {
   uint16_t r;
   r = analogRead(PIN_KB);
   if (isKbPressed(r, ADC_UP)) {
      return KEY_UP;
   }
   if (isKbPressed(r, ADC_DOWN)) {
      return KEY_DOWN;
   }
   if (isKbPressed(r, ADC_LEFT)) {
      return KEY_BACK;
   }
   if (isKbPressed(r, ADC_RIGHT)) {
      return KEY_OK;
   }
#if SHOW_DEBUG
#if 0
   else if (r > 20) {
     Serial.println(r,DEC);
   }
#endif
#endif
   return 0;
}


// Checks whether the power switch is on by checking an aanlogue
// value on VCC_DETECT pin.
static uint8_t checkPowerOn() {
    uint16_t r;
    r = analogRead(PIN_VCC_DETECT);
    if (r > 300) {
        return 1;
    } else {
        return 0;
    }
}

// Wait till no key is pressed
static void waitForKeyRelease() {
    while (checkKb()) delay(50);
}

// Show inital information and the version string.
void showSplashScreen() {
  oled_draw_h_line(0, 63, 23, 1);
  oled_set_y(24);
  oled_draw_string(" LTS74X20", true);

  oled_set_y(40);
  oled_draw_string("74X LOGIC", false);
  oled_set_y(50);
  oled_draw_string(" TESTER", false);

  oled_set_y(80);
  oled_draw_string(VERSION, false);
}

#if TEST_KEYS
// This function checks keyboard and prints pressed key values on the OLED screen.
// Use it if the keys do not seem to work.
static void testKeys() {
  char buf[12] = { 'K', 'E', 'Y', ':'};

  oled_clear_display();
  while (true) {
    uint16_t r;
    r = analogRead(PIN_KB);

    buf[4] = r > 1000 ? '0' + (r /1000) : ' ';
    r %= 1000;
    buf[5] = r >= 100 ? '0' + (r /100) : '0';
    r %= 100;
    buf[6] = r >= 10 ? '0' + (r /10) : '0';
    r %= 10;
    buf[7] = '0' + r;
    buf[8] = 0;        
    
    oled_set_y(24);
    oled_draw_string(buf, false);
    delay(100);
  }
}
#endif /* TEST_KEYS */
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
void loop() {
    switch (state) {
      case STATE_MENU:
        handleMenu();
        break;
      case STATE_TEST:
        handleTest();
        break;
      case STATE_PINOUT:
        handlePinout();
        break;
      case STATE_SHOW_ERRORS:
        handleErrorScreen();
        break;
      case STATE_SCREEN_SAVER:
        handleScreenSaver();
        break;
    }
}

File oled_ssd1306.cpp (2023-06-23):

/*
*****************************************************************************
Based on Deneyap OLED library v 1.0.3
*****************************************************************************
*/

#include "oled_ssd1306.h"

/*
There are some SSD1306 OLED displays with a buggy controller which do not
properly increment Y position in vertical mode.  These seem to be SSD1306 clones 
with modern/crispier OLED screen. The display PCB of these clones is a few
mm smaller than the original (mounting hole pitch does not match).
Because of these buggy controllers the Vertical mode is not used. 
Instead, the Vertical mode is simulated in Horizontal mode by setting a vertical
clip of exactly one column.

If you ask where is the frame buffer, then there is none. The text pixels are drawn directly
to the controller. We use a 8 byte line buffer comprising a single vertical line to speed
up the data transfers and rendering.
*/


#define FONT_DATA_OFFSET 2


#define SSD1306_Command_Mode          0x80
#define SSD1306_Data_Mode             0x40
#define SSD1306_Display_Off_Cmd       0xAE
#define SSD1306_Display_On_Cmd        0xAF
#define SSD1306_Normal_Display_Cmd    0xA6
#define SSD1306_Inverse_Display_Cmd   0xA7
#define SSD1306_Set_Brightness_Cmd    0x81

static const uint8_t *m_font;     // Current font.
static uint8_t m_address;         // I2C address
static uint8_t m_font_width;      // Font witdth.
static uint8_t m_draw_pos;        // screen position - current column

static void send_command(unsigned char command) {
  Wire.beginTransmission(m_address); // begin I2C communication
  Wire.write(SSD1306_Command_Mode); // Set OLED Command mode
  Wire.write(command);
  Wire.endTransmission(); // End I2C communication
}

static void reset_segment() {
  Wire.beginTransmission(m_address);
  Wire.write(SSD1306_Command_Mode);
  Wire.write(0x22);
  Wire.write(SSD1306_Command_Mode);
  Wire.write(0);
  Wire.write(SSD1306_Command_Mode);
  Wire.write(7);
  Wire.endTransmission();
}

static void send_data(unsigned char* data, unsigned char len) {
  uint8_t resetSegment = len != 8;

  Wire.beginTransmission(m_address);
  if (m_draw_pos != 0xFF) {
      // set the clip region to be exactly one column (simulating vertical mode)
      Wire.write(SSD1306_Command_Mode);
      Wire.write(0x21);
      Wire.write(SSD1306_Command_Mode);
      Wire.write(m_draw_pos);
      Wire.write(SSD1306_Command_Mode);
      Wire.write(m_draw_pos);
  }

  //send pixel data
  Wire.write(SSD1306_Data_Mode); 
  while (len--) {
      Wire.write(*data);
      data++;
  }
  m_draw_pos++;
  Wire.endTransmission();

  if (resetSegment) {
      reset_segment();
  }
}


static void oled_init(void) {
  send_command(0xAE); // display off
  send_command(0xA6); // Set Normal Display (default)
  send_command(0xAE); // DISPLAYOFF
  send_command(0xD5); // SETDISPLAYCLOCKDIV
  send_command(0x80); // the suggested ratio 0x80
  send_command(0xA8); // SSD1306_SETMULTIPLEX
  send_command(0x3F);
  send_command(0xD3);       // SETDISPLAYOFFSET
  send_command(0);
  send_command(0x40 | 0x0); // SETSTARTLINE
  send_command(0x8D);       // CHARGEPUMP
  send_command(0x14);
  send_command(0xA1); // SEGREMAP   Mirror screen horizontally (A0)
  send_command(0xC8); // COMSCANDEC Rotate screen vertically (C0)
  send_command(0xDA); // 0xDA
  send_command(0x12); // COMSCANDEC
  send_command(0x81); // SETCONTRAST
  send_command(0xCF); //
  send_command(0xd9); // SETPRECHARGE
  send_command(0xF1);
  send_command(0xDB); // SETVCOMDETECT
  send_command(0x40);
  send_command(0xA4); // DISPLAYALLON_RESUME
  send_command(0xA6); // NORMALDISPLAY
  send_command(0x2E); // Stop scroll
  send_command(0x20); // Set Memory Addressing Mode
  send_command(0); // Horizontal mode - for compatibility. Some OLED display clones do not support vertical mode

  
  m_font = font_custom;
  m_font_width = pgm_read_byte(&m_font[0]);
  oled_clear_display();
}

bool oled_begin(uint8_t address, TwoWire &wirePort) {
  m_address = address >> 1;
  Wire.begin();
  Wire.setClock(400000UL);
  oled_init();
  if (!Wire.endTransmission())
    return true;
  return false;
}

void oled_clear_display(void) {
  uint8_t data[8] = {0, 0, 0, 0, 0, 0, 0, 0 };
  unsigned char i, j;
  oled_set_y(0);
  send_command(SSD1306_Display_Off_Cmd); // display off
  for (j = 0; j < 128; j++) {
    send_data(data, 8);
  }
  send_command(SSD1306_Display_On_Cmd); // display on
}




void oled_set_brightness(unsigned char brightness) {
  send_command(SSD1306_Set_Brightness_Cmd);
  send_command(brightness);
}


void oled_set_y(unsigned char y) {
  m_draw_pos = y;
}


static void draw_glyph_line(uint8_t* buf, uint8_t l, uint8_t x) {
  uint8_t i = 0;
  uint8_t offset = 7 - (x >> 3); // 8 bytes per row
  uint8_t maskX = 1 << (7 - (x & 0b111));
  while (i < 7) { //font glyph  is 7 pixels high
    //pixel should be drawn
    if ((1 << i) & l) {
      buf[offset] |= maskX;
    }
    offset += 8; //display width in bytes (64 pixels / 8)
    i++;
  }
}

static void draw_glyph_line_inv(uint8_t* buf, uint8_t l, uint8_t x) {
  uint8_t i = 0;
  uint8_t offset = 7 - (x >> 3); // 8 bytes per row
  uint8_t maskX = 1 << (7 - (x & 0b111));
  while (i < 8) { //font glyph  is 7 pixels high + 1 bottom line
    //pixel should be drawn
    if (!((1 << i) & l)) {
      buf[offset] |= maskX;
    }
    offset += 8; //display width in bytes (64 pixels / 8)
    i++;
  }
}

void oled_draw_string(char* text, bool inverse) {
  uint8_t buf[8 * 8]= {0};
  uint8_t i = 0, j;
  uint8_t x = 0;

  while (text[i]) {
    uint16_t index = (text[i] - 32) * m_font_width +  FONT_DATA_OFFSET;
    for (j = 0; j < m_font_width; j++) {
      uint8_t l = pgm_read_byte(&m_font[index]);
      if (inverse) {
        draw_glyph_line_inv(buf, l, x);
      } else {
        draw_glyph_line(buf, l, x);
      }
      x++;
      index++;
    }
    if (inverse) {
      draw_glyph_line_inv(buf, 0x0, x); //draw bottom line
    }
    x++;
    i++;
  }

  for (i = 0; i < 56; i += 8) {
    send_data(buf + i, 8);
  }
  if (inverse) {
    send_data(buf + 56, 8);
  }

}

void oled_draw_h_line(unsigned char x1, unsigned char x2, unsigned char y, unsigned char color) {
  uint8_t i, s = 255, cnt = 0;
  uint8_t buf[8]= {0};

  while (x1 < x2) {
    i = 63 - x1;
    buf[i >> 3] |= 1 << ((i & 0b111));
    x1++;
  }
  i = 0;
  while (i < 8) {
    if (buf[i] != 0) {
      if (s == 255) {
        s = i;
      }
      cnt++;
    }
    i++;
  }

  m_draw_pos = y;
  cnt += s;
  s = 0;
  
  if (color) {
    send_data(buf + s, cnt);
  } else {
    uint8_t buf2[8]= {0};
    send_data(buf2 + s, cnt);
  }
}
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

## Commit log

2023-06-23 Initial Arduino code, Kicad design, schematic and gerbers.
    [lts74x.kicad_pcb, lts74x.kicad_sch]
2023-07-23 img: added Arduino Nano image with the serial mod
2023-07-23 Update README.md
    added link to the Arduino Nano mods image
2023-07-23 added bom.txt
